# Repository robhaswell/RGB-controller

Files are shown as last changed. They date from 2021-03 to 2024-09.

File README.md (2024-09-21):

# RGB-controller
A 10-channel RGB controller based on the ESP32 microcontroller

**Important:** I have successfully ordered and assembled this project, but since then I altered the 47uF capacitor package so that it is not an *extended part* at JLCPCB. The author accepts NO RESPONSIBILITY for this product working, and it has not undergone extensive safety testing. Use at your own risk.

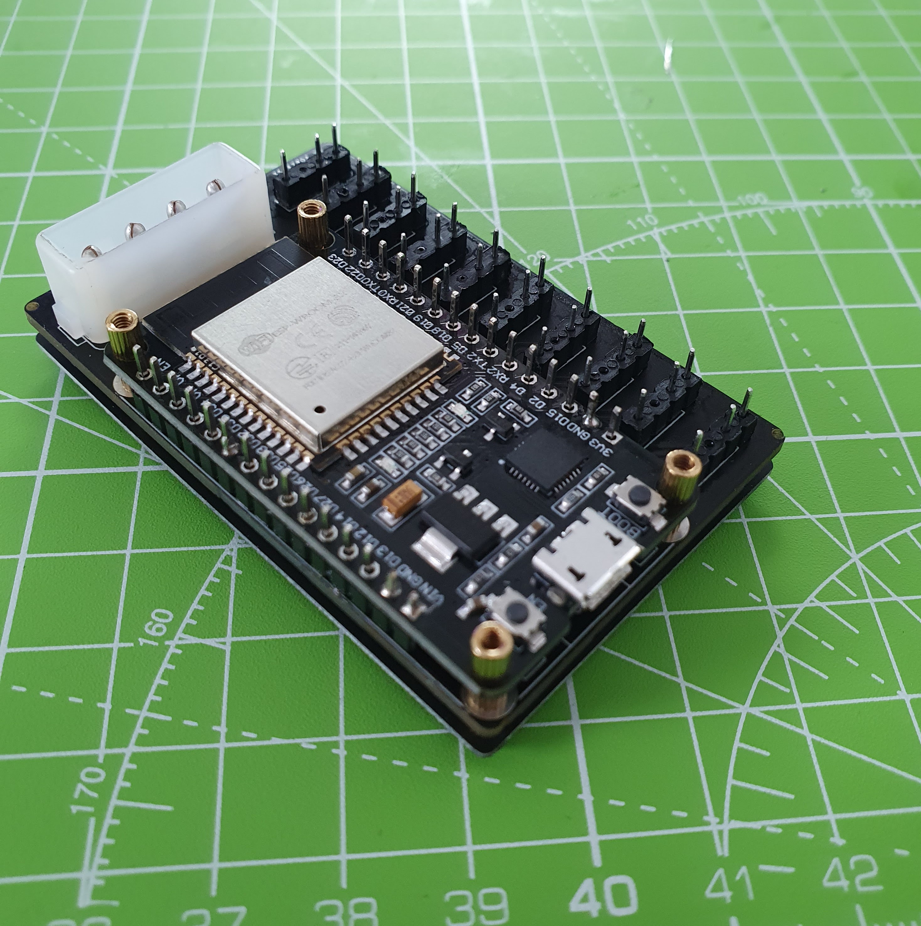
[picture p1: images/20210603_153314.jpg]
Opened finished build

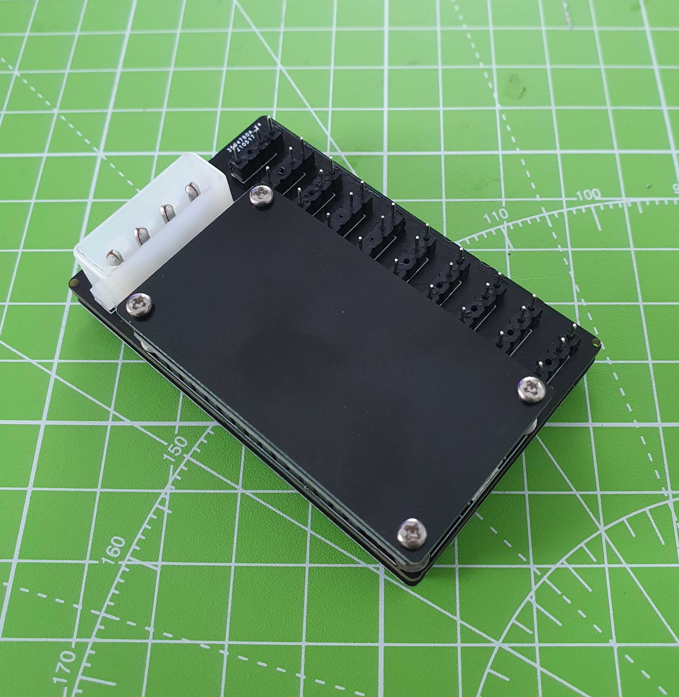
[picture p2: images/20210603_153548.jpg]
Finished with top plate

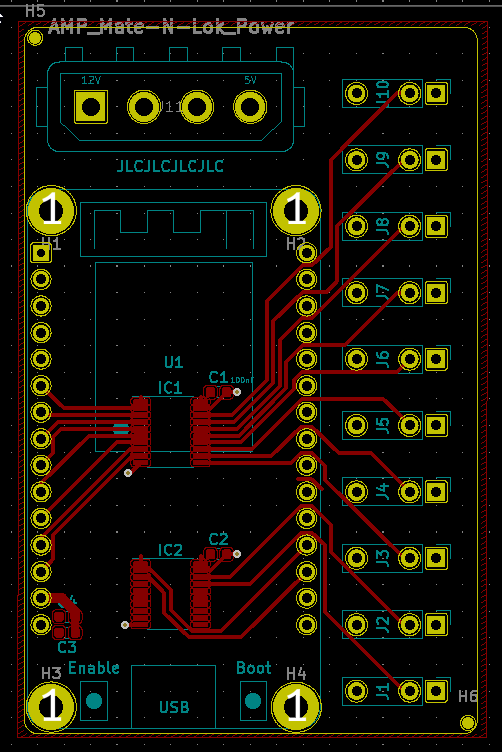
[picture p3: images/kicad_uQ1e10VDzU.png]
PCB layout

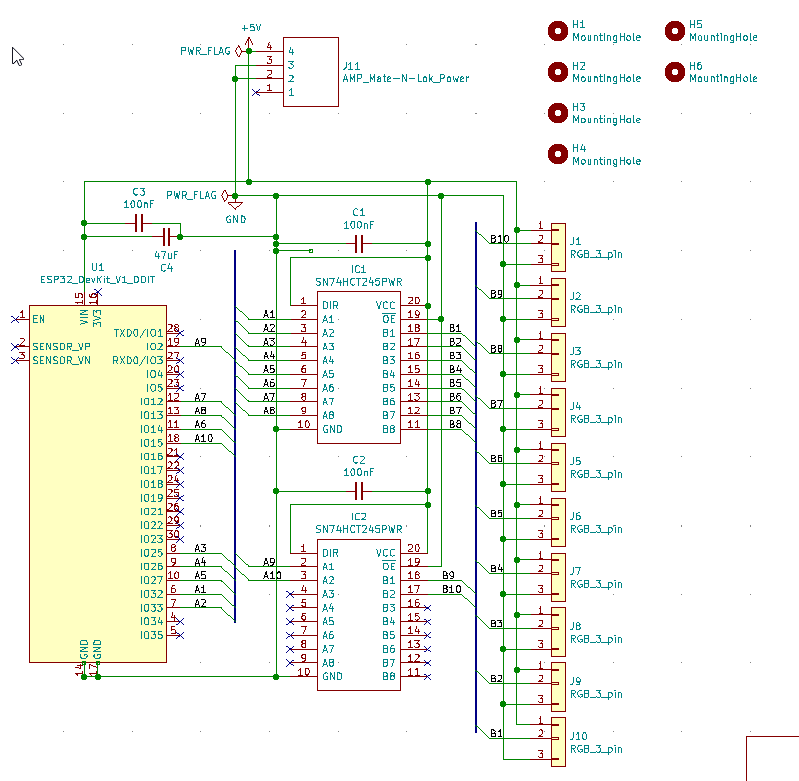
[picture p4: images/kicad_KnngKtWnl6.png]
Electrical schematics


# Ordering the PCB
To order the PCB at [JLCPCB](https://jlcpcb.com) you will need to do the following steps:

1. Submit `/gerber.zip` as your job
2. Choose the following options:
    1. PCB Color: Black
    2. Remove Order Number: Specify a location
3. Enable SMT Assembly and choose:
    1. Top side
    2. SMT QTY: 2 or 5 depending on your needs.
    3. Tooling holes: Added by Customer
4. Confirm
5. Upload files:
    1. BOM File: `/JLC/Controller.csv`
    2. CPL File: `/JLC/Controller-top-pos.csv`
6. Click through to the end
7. To order the top and bottom plates (high recommended), make two more orders with `plates/gerber-top.zip` and `plates/gerber-bottom.zip` - no SMT Assembly required
    1. PCB Thickness: Can be as low as 1.0mm but I recommend leaving it at 1.6mm
    2. Remove Order Number: Not necessary, I recommend No, but you could choose Yes

** **MAKE SURE YOU CHOOSE THE CHEAPEST SHIPPING OPTION!!** **.

Final discounts will be applied right before you pay, including free SMT Assembly. The final cost should be around $30 but it varies.

## Components

Component | Quantity | Link
-|-|-
ESP32 Devkit v1 (DOIT) | 1 | https://www.aliexpress.com/item/1005001648850998.html
3-pin RGB needle adapter | 10 | https://www.aliexpress.com/item/1005005743425681.html
350211-1 Mate-N-Lok connector | 1 | Find these locally - search "350211-1" at your local electronics store, or check Ebay sellers in your area. You may know this better as a "Molex connector".
M2 standoff, 4mm, male-female | 12 or 20 | https://www.aliexpress.com/item/1005002542327479.html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 or locally. Order 20 if not using screws (see next).
Optional: M2 screws and nuts | 4 | You can also find these on Aliexpress, or with the above spacers in kits on Amazon, etc. To keep costs down you can use use 20 male-female standoffs, but screws + nuts (or 4x female-female standoffs) will be neater.

## Build
Soldering and construction order order I would recommend:

### 1. RGB headers
10x RGB pin headers should come first.
You will need to remove or clip one pin from each header.
To pull them out I recommend using pliers to push the pins through.
You can also grab the pin with pliers and use your iron to heat it from the other side, this will free it from the plastic.

Preparing these pin headers is by far the most time consuming part of the assembly.

**Protip**: Place all 10 pin headers on your PCB, then place one of your spare PCBs over the top.
You might want to line up the pin headers on one side, and then wiggle the binding ones until they enter the mounting holes.
This will help you to get 10x headers which are nicely lined up and evenly spaced.

### 2. PCB standoffs
Most standoffs do not pass through the holes on the ESP32 devkit, so they will need adding to the PCB before the ESP32 devkit is soldered on top.

### 3. ESP32 devkit
Next, solder this to the board using the included pin headers. You might optionally want to use the standoffs to fix it to the PCB while soldering. You will also need to clip the headers after it is soldered.

### 4. 350211-1 Mate-N-Lok connector ("Molex connector")
Finally you can solder the power connector, make sure to use plenty of solder on this one.

### 5. Screw it all together
Screw on your top and bottom plates. These will be important in protecting your RGB controller and preventing shorts.

## Loading the firmware
The final step is to load the firmware in accordance with instructions on the WLED wiki: https://github.com/Aircoookie/WLED/wiki

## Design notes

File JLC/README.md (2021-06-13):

# JLC assembly files
These files are required for SMT assembly at JLCPCB.

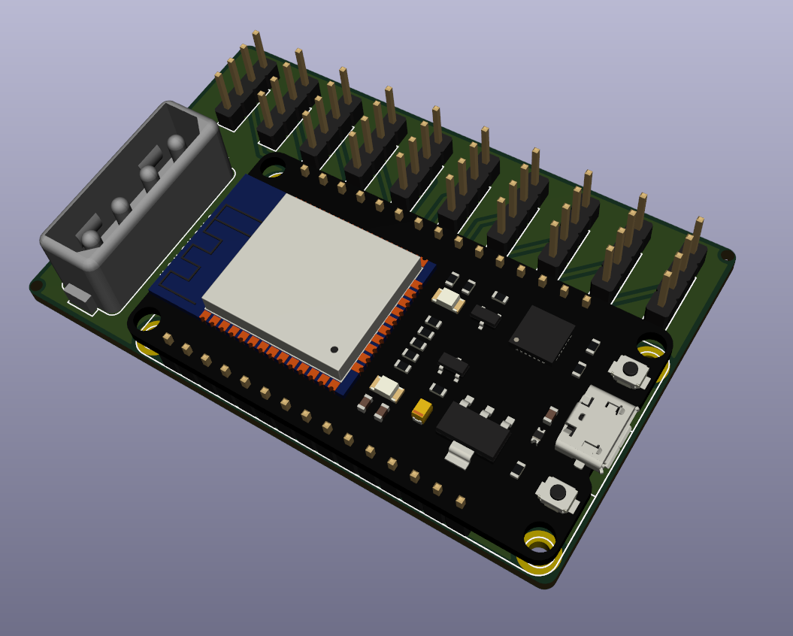
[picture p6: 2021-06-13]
images/kicad_PlrLsKIdt9.png

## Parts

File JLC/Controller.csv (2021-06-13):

Comment | Designator | Footprint | LCSC
100nF | C1 | 0603 | C14663
100nF | C2 | 0603 | C14663
100nF | C3 | 0603 | C14663
47uF | C4 | 0603 | C140782
SN74HCT245PWR | IC1 | TSSOP-20_4.4x6.5x0.65P | C6779
SN74HCT245PWR | IC2 | TSSOP-20_4.4x6.5x0.65P | C6779

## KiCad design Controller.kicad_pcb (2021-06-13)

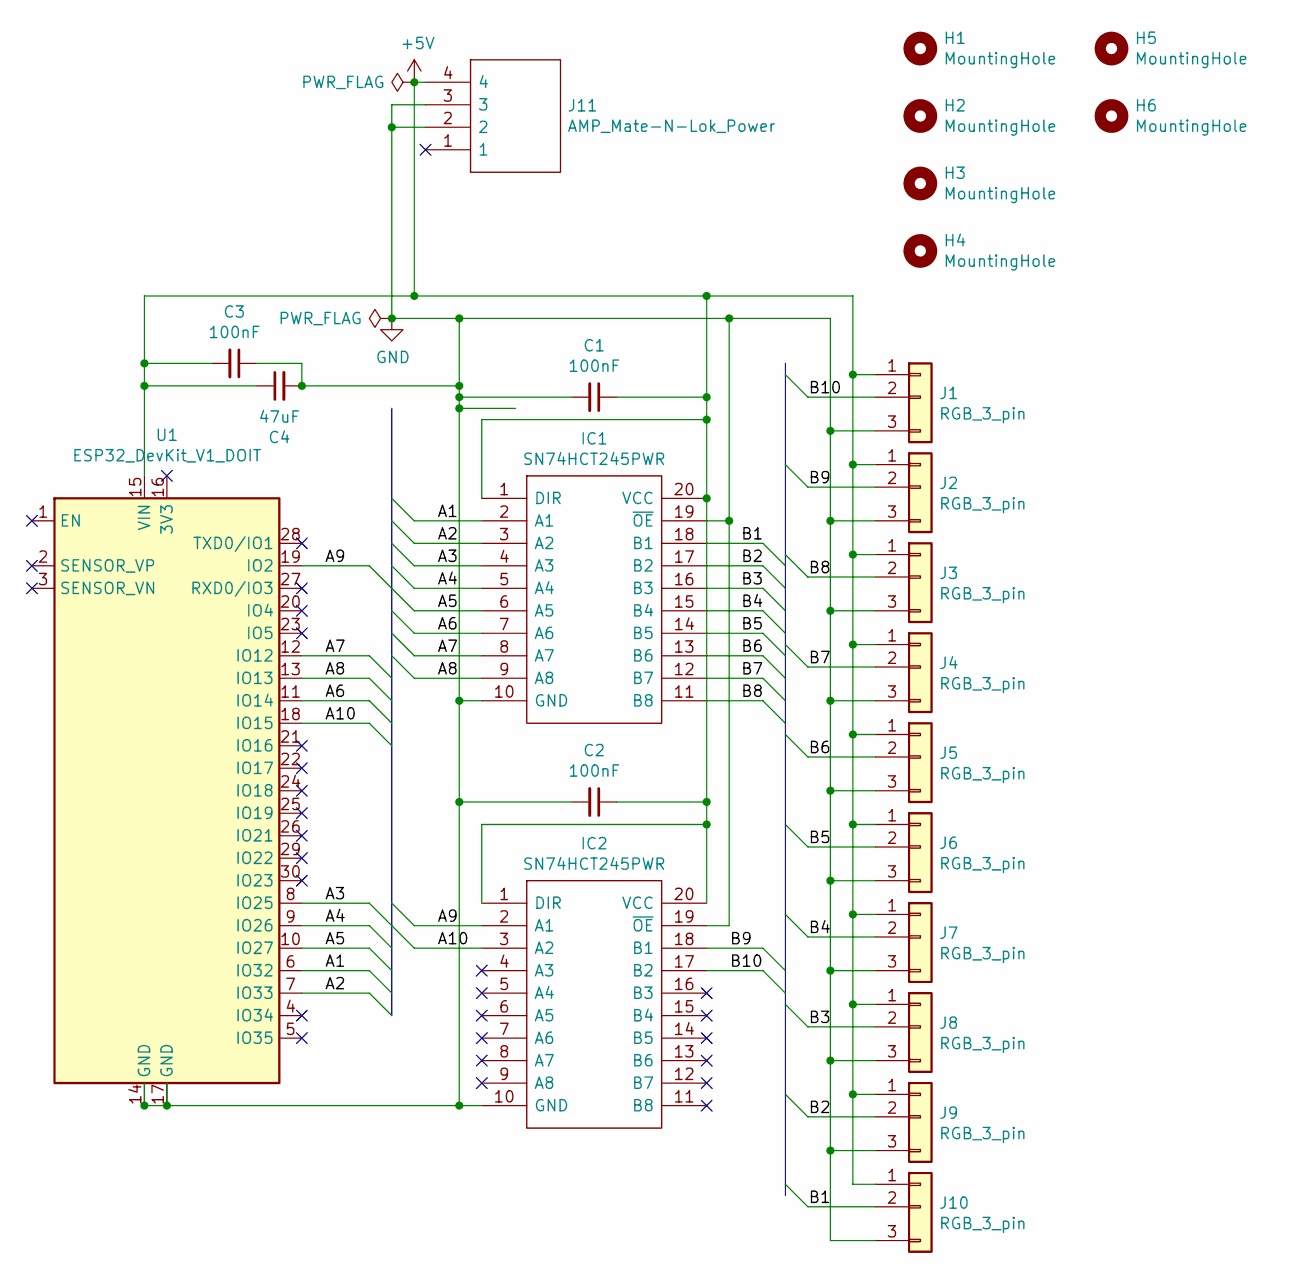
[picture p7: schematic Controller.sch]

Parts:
C1, C2, C3: 100nF; C_0603_1608Metric
C4: 47uF; C_1206_3216Metric
H1, H2, H3, H4: MountingHole; MountingHole_2.2mm_M2
H5, H6: MountingHole; ToolingHole_1.152mm
IC1, IC2: SN74HCT245PWR; TSSOP-20_4.4x6.5mm_P0.65mm; Manufacturer_Part_Number SN74HCT245PWR; Mouser Part Number 595-SN74HCT245PWR
J1, J2, J3, J4, J5, J6, J7, J8, J9, J10: RGB_3_pin; RGB_3-Pin
J11: AMP_Mate-N-Lok_Power; TE_MATE-N-LOK_1-794374-x_1x01_P4.14mm_Horizontal; Manufacturer_Part_Number 350211-1
U1: ESP32_DevKit_V1_DOIT; esp32_devkit_v1_doit

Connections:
+5V: C1.1, C2.1, C3.2, C4.1, IC1.1 (DIR), IC1.20 (VCC), IC2.1 (DIR), IC2.20 (VCC), J1.1, J2.1, J3.1, J4.1, J5.1, J6.1, J7.1, J8.1, J9.1, J10.1, J11.4, U1.15 (VIN)
/A1: IC1.2 (A1), U1.6 (IO32)
/A2: IC1.3 (A2), U1.7 (IO33)
/A3: IC1.4 (A3), U1.8 (IO25)
/A4: IC1.5 (A4), U1.9 (IO26)
/A5: IC1.6 (A5), U1.10 (IO27)
/A6: IC1.7 (A6), U1.11 (IO14)
/A7: IC1.8 (A7), U1.12 (IO12)
/A8: IC1.9 (A8), U1.13 (IO13)
/A9: IC2.2 (A1), U1.19 (IO2)
/A10: IC2.3 (A2), U1.18 (IO15)
/B1: IC1.18 (B1), J10.2
/B2: IC1.17 (B2), J9.2
/B3: IC1.16 (B3), J8.2
/B4: IC1.15 (B4), J7.2
/B5: IC1.14 (B5), J6.2
/B6: IC1.13 (B6), J5.2
/B7: IC1.12 (B7), J4.2
/B8: IC1.11 (B8), J3.2
/B9: IC2.18 (B1), J2.2
/B10: IC2.17 (B2), J1.2
GND: C1.2, C2.2, C3.1, C4.2, IC1.10 (GND), IC1.19 (~OE), IC2.10 (GND), IC2.19 (~OE), J1.3, J2.3, J3.3, J4.3, J5.3, J6.3, J7.3, J8.3, J9.3, J10.3, J11.2, J11.3, U1.14 (GND), U1.17 (GND)

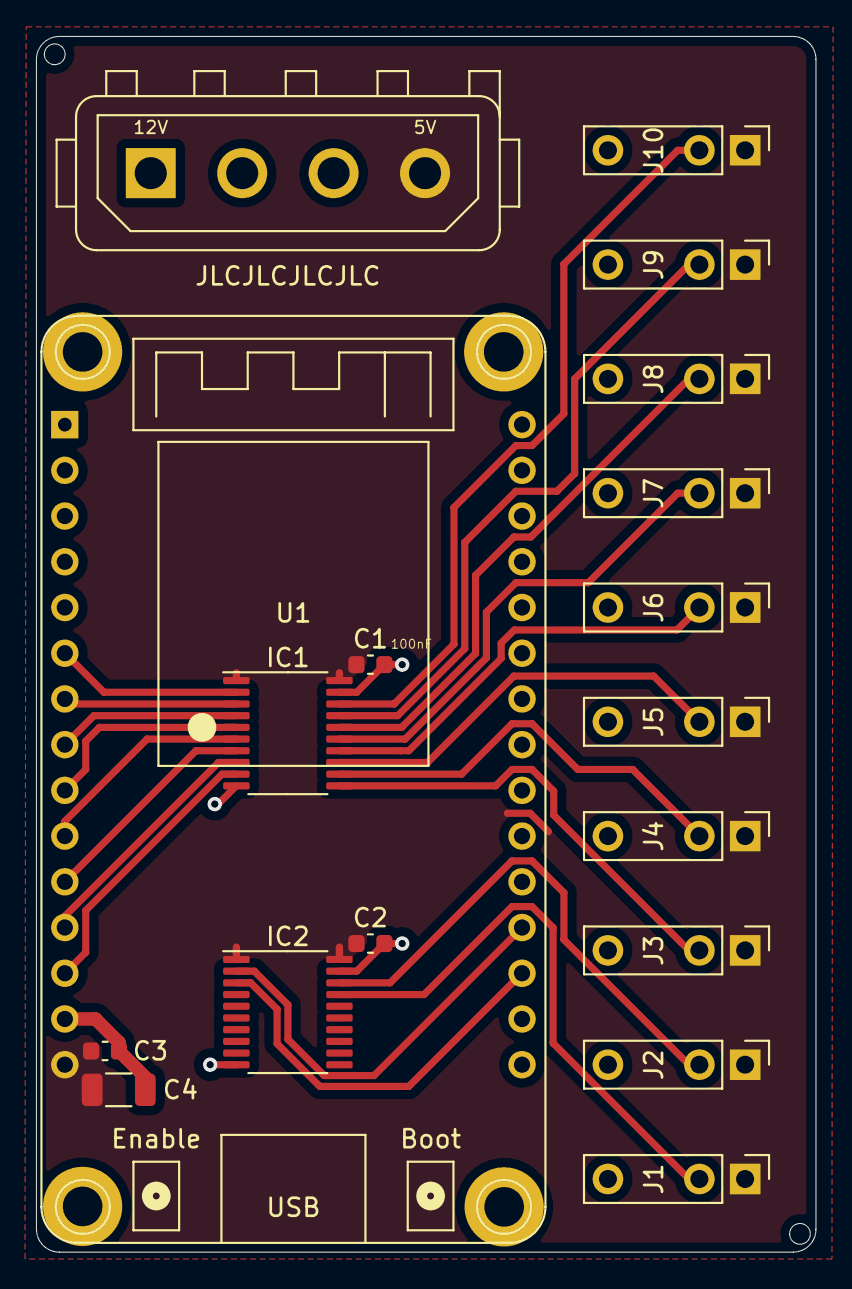
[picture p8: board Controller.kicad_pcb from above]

Board: 2 copper layers, 43.3 x 67.5 mm, 24 parts (0 on the bottom side), 22 nets.

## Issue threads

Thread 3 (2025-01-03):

WLED pins can't be used

mrgadget, 2025-01-03:
Hi - have flashed the latest WLED and get an error where the GPIO pins related to outputs 1, 6 & 10 aren't able to be used by WLED - have you come up against this?

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

I realise this is a WLED issue not your hardware, but I just wondered if you'd figured out a way around this so you can use all 10 channels.

Thanks,
Ben.

mrgadget, 2025-01-03:
I've fixed this myself, but will leave the fix here in case it helps someone else - I found the issue under `Usermods` section in WLED settings - `Digitalmic` defaults to using competing pins.  Setting these pins to `unused` frees them up for use for LED lines.

Closed 2025-01-03.

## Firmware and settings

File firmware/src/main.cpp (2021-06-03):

#include <Arduino.h>
#include <WiFi.h>
#include <FastLED.h>
#include <ArduinoOTA.h>

#include "wifi_secrets.h"

#define DELAY 200
#define NUM_ZONES 8
#define NUM_LEDS 24

#define J1 13
#define J2 12
#define J3 14
#define J4 27
#define J5 26
#define J6 25
#define J7 33
#define J8 32

#define FOR_LOOP_ZONES for (int zone_i = 0; zone_i < NUM_ZONES; zone_i++)  \
  {                                                                        \
    for (int led_i = 0; led_i < NUM_LEDS; led_i++) {


const char* ssid = SECRET_SSID;
const char* password = SECRET_PASS;


CRGB zones[NUM_ZONES][NUM_LEDS];

// RGB functions
void identify_leds() {
  FOR_LOOP_ZONES
    zones[zone_i][led_i].setRGB(255, 0, 255);
    FastLED.show();
    delay(20);

    zones[zone_i][led_i].setRGB(0, 0, 0);
    FastLED.show();
    // delay(10);
  } }
  delay(500);
}

void cycle_hues() {
  static uint8_t start_hue = 0;
  uint8_t hue = start_hue;
  start_hue++;

  for (int i = 0; i < NUM_ZONES; i++)
  {
    for (int j = 0; j < NUM_LEDS; j++) {
      zones[i][j].setHSV(hue, UINT8_MAX, UINT8_MAX);
      hue += 3;
    }
  }
}

uint8_t synthwave_fan_hue(uint8_t start_hue, int step, int ring_offset, int fan_i, int led_i) {
  uint8_t hue = start_hue - (fan_i * step);
  if (led_i >= 8)
    // Ring LED
    hue += ring_offset;
  return hue;
}

void synthwave() {
  FOR_LOOP_ZONES
    uint8_t hue;
    if (zone_i <= 2) {
      // Side fans starting from the top
      hue = synthwave_fan_hue(20, 6, 8, zone_i, led_i);
    } else if (zone_i <= 5) {
      // Bottom fans starting from the left
      hue = synthwave_fan_hue(224, 32, -20, zone_i-3, led_i);
    } else if (zone_i == 6) {
      // Reservoir starting from the bottom
      hue = 156;
    } else if (zone_i == 7) {
      // GPU & CPU starting from the left
      // hue = 20 - led_i;
      hue = 12 + led_i;
    }
    zones[zone_i][led_i].setHSV(hue, UINT8_MAX, UINT8_MAX);
  } }
}

void connectToNetwork() {
  WiFi.begin(ssid, password);

  while (WiFi.status() != WL_CONNECTED) {
    delay(1000);
    Serial.println("Establishing connection to WiFi..");
  }

  Serial.println("Connected to network");
  Serial.println(WiFi.localIP());
}

void initOTA() {
  Serial.println("Initializing OTA");

  ArduinoOTA
  .onStart([]() {
    String type;
    if (ArduinoOTA.getCommand() == U_FLASH)
      type = "sketch";
    else // U_SPIFFS
      type = "filesystem";

    // NOTE: if updating SPIFFS this would be the place to unmount SPIFFS using SPIFFS.end()
    Serial.println("Start updating " + type);
  })
  .onEnd([]() {
    Serial.println("\nEnd");
  })
  .onProgress([](unsigned int progress, unsigned int total) {
    Serial.printf("Progress: %u%%\r", (progress / (total / 100)));
  })
  .onError([](ota_error_t error) {
    Serial.printf("Error[%u]: ", error);
    if (error == OTA_AUTH_ERROR) Serial.println("Auth Failed");
    else if (error == OTA_BEGIN_ERROR) Serial.println("Begin Failed");
    else if (error == OTA_CONNECT_ERROR) Serial.println("Connect Failed");
    else if (error == OTA_RECEIVE_ERROR) Serial.println("Receive Failed");
    else if (error == OTA_END_ERROR) Serial.println("End Failed");
  });

  ArduinoOTA.begin();

  Serial.println("OTA ready");
}

void setup() {
  Serial.begin(115200);

  FastLED.addLeds<NEOPIXEL, J1>(zones[0], NUM_LEDS);
  FastLED.addLeds<NEOPIXEL, J2>(zones[1], NUM_LEDS);
  FastLED.addLeds<NEOPIXEL, J3>(zones[2], NUM_LEDS);
  FastLED.addLeds<NEOPIXEL, J4>(zones[3], NUM_LEDS);
  FastLED.addLeds<NEOPIXEL, J5>(zones[4], NUM_LEDS);
  FastLED.addLeds<NEOPIXEL, J6>(zones[5], NUM_LEDS);
  FastLED.addLeds<NEOPIXEL, J7>(zones[6], NUM_LEDS);
  FastLED.addLeds<NEOPIXEL, J8>(zones[7], NUM_LEDS);

  FastLED.clear(true);

  connectToNetwork();

  initOTA();
}

void loop() {
  ArduinoOTA.handle();

  // Update LED colors
  synthwave();

  FastLED.show();
  delay(DELAY);
}

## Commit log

2021-03-21 Initial commit.
    [Simplified RGB Controller.kicad_pcb, Simplified RGB Controller.sch]
2021-03-21 * Incoporate feedback * The ESP32 takes 12V on VIN
    [Simplified RGB Controller.kicad_pcb, Simplified RGB Controller.sch]
2021-03-22 Update to match parts available at JCL.
    [Simplified RGB Controller.kicad_pcb, Simplified RGB Controller.sch]
2021-03-22 Rename project and create manufacturing files.
    [Controller-B_Cu.gbr, Controller-B_Mask.gbr, Controller-B_Paste.gbr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]
2021-03-22 Add top and bottom plate files.
    [Controller.kicad_pcb]
2021-03-23 Files for the case.
    [Controller-Bottom.kicad_pcb, Controller-Top.kicad_pcb]
2021-04-26 Backup schematics for ESP32.
2021-04-26 Basic firmware which sets LED values, connects to WiFi and enables OTA updates.
2021-05-01 Hide wifi configuration and prevent autogenerated files from being added to the repo.
    [main.cpp]
2021-05-04 More compact layout with 10 channels.
    [Controller.kicad_pcb, Controller.sch]
2021-05-16 Update controller to new design.
    [Controller.kicad_pcb, Controller.sch]
2021-05-16 Reorganise JLC exports.
    [Controller.csv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]
2021-05-16 Manufacturing files.
    [Controller-B_Cu.gbr, Controller-B_Mask.gbr, Controller-B_Paste.gbr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]
2021-05-16 Top and bottom plates.
    [Controller.kicad_pcb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]
2021-06-13 Port firmware to WLED but add a note.
    [colours.csv]
2021-06-13 Use 47uF capacitor which is available in JLC's basic library.
    [Controller-B_Cu.gbr, Controller-B_Mask.gbr, Controller-B_Paste.gbr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]
